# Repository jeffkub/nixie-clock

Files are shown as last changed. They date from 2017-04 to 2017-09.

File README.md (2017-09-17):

# nixie-clock

An open source nixie clock with GPS time synchronization.

## Enclosure

The enclosure design has been moved to Fusion 360.  The files in the hardware folder are out of date and will be removed at some point.

1. [Enclosure](http://a360.co/2x962o5)
2. [PCB](http://a360.co/2x9v2f3)
3. [Assembly](http://a360.co/2y7SgBr)

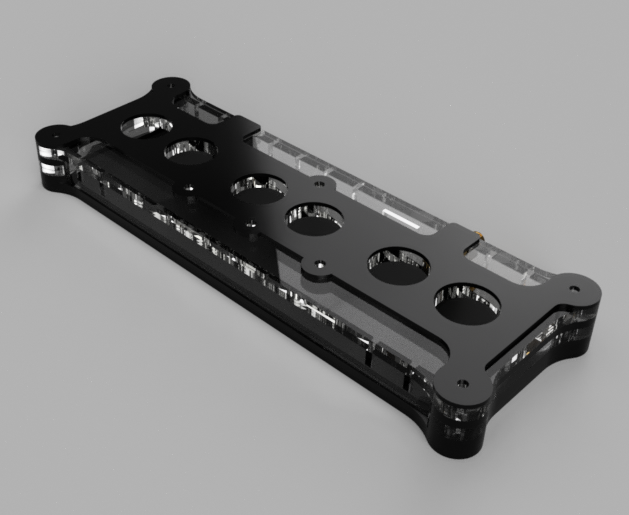
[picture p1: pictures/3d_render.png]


## Build Instructions

The code was built on Ubuntu 16.04.  The [STM32Cube F3 library V1.9.0](http://www.st.com/content/st_com/en/products/embedded-software/mcus-embedded-software/stm32-embedded-software/stm32cube-embedded-software/stm32cubef3.html) will need to be installed to the `/opt/` directory.  The following apt packages are required.

```
cmake
gcc-arm-none-eabi
gdb-arm-none-eabi
```

To build the code.

```bash
mkdir firmware/nixie-clock/release
cd firmware/nixie-clock/release
cmake -DSTM32_CHIP=STM32F302C8 -DCMAKE_TOOLCHAIN_FILE=../../cmake/gcc_stm32.cmake -DSTM32Cube_DIR=/opt/STM32Cube_FW_F3_V1.9.0/ -DCMAKE_BUILD_TYPE=Release ..
make
```

To build for debugging.

```bash
mkdir firmware/nixie-clock/debug
cd firmware/nixie-clock/debug
cmake -DSTM32_CHIP=STM32F302C8 -DCMAKE_TOOLCHAIN_FILE=../../cmake/gcc_stm32.cmake -DSTM32Cube_DIR=/opt/STM32Cube_FW_F3_V1.9.0/ -DCMAKE_BUILD_TYPE=Debug ..
make
```

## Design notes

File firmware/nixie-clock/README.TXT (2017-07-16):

cmake -DSTM32_CHIP=STM32F302C8 -DCMAKE_TOOLCHAIN_FILE=../../cmake/gcc_stm32.cmake -DSTM32Cube_DIR=/opt/STM32Cube_FW_F3_V1.9.0/ -DCMAKE_BUILD_TYPE=Debug ..

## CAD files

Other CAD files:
mechanical/NixieClock.dwg
mechanical/Back.ipt
mechanical/Base1.ipt
mechanical/Base2.ipt
mechanical/Bumper.ipt
mechanical/Cover.ipt
mechanical/Front.ipt
mechanical/IN-14.ipt
mechanical/M3Nut.ipt
mechanical/M3x25mm.ipt
mechanical/MainPCB.ipt
mechanical/NixieClock.iam
mechanical/PCB.iam
mechanical/Side.iam
mechanical/Spacer1.ipt
mechanical/Spacer2.ipt
mechanical/Top.ipt
mechanical/TubePCB.ipt

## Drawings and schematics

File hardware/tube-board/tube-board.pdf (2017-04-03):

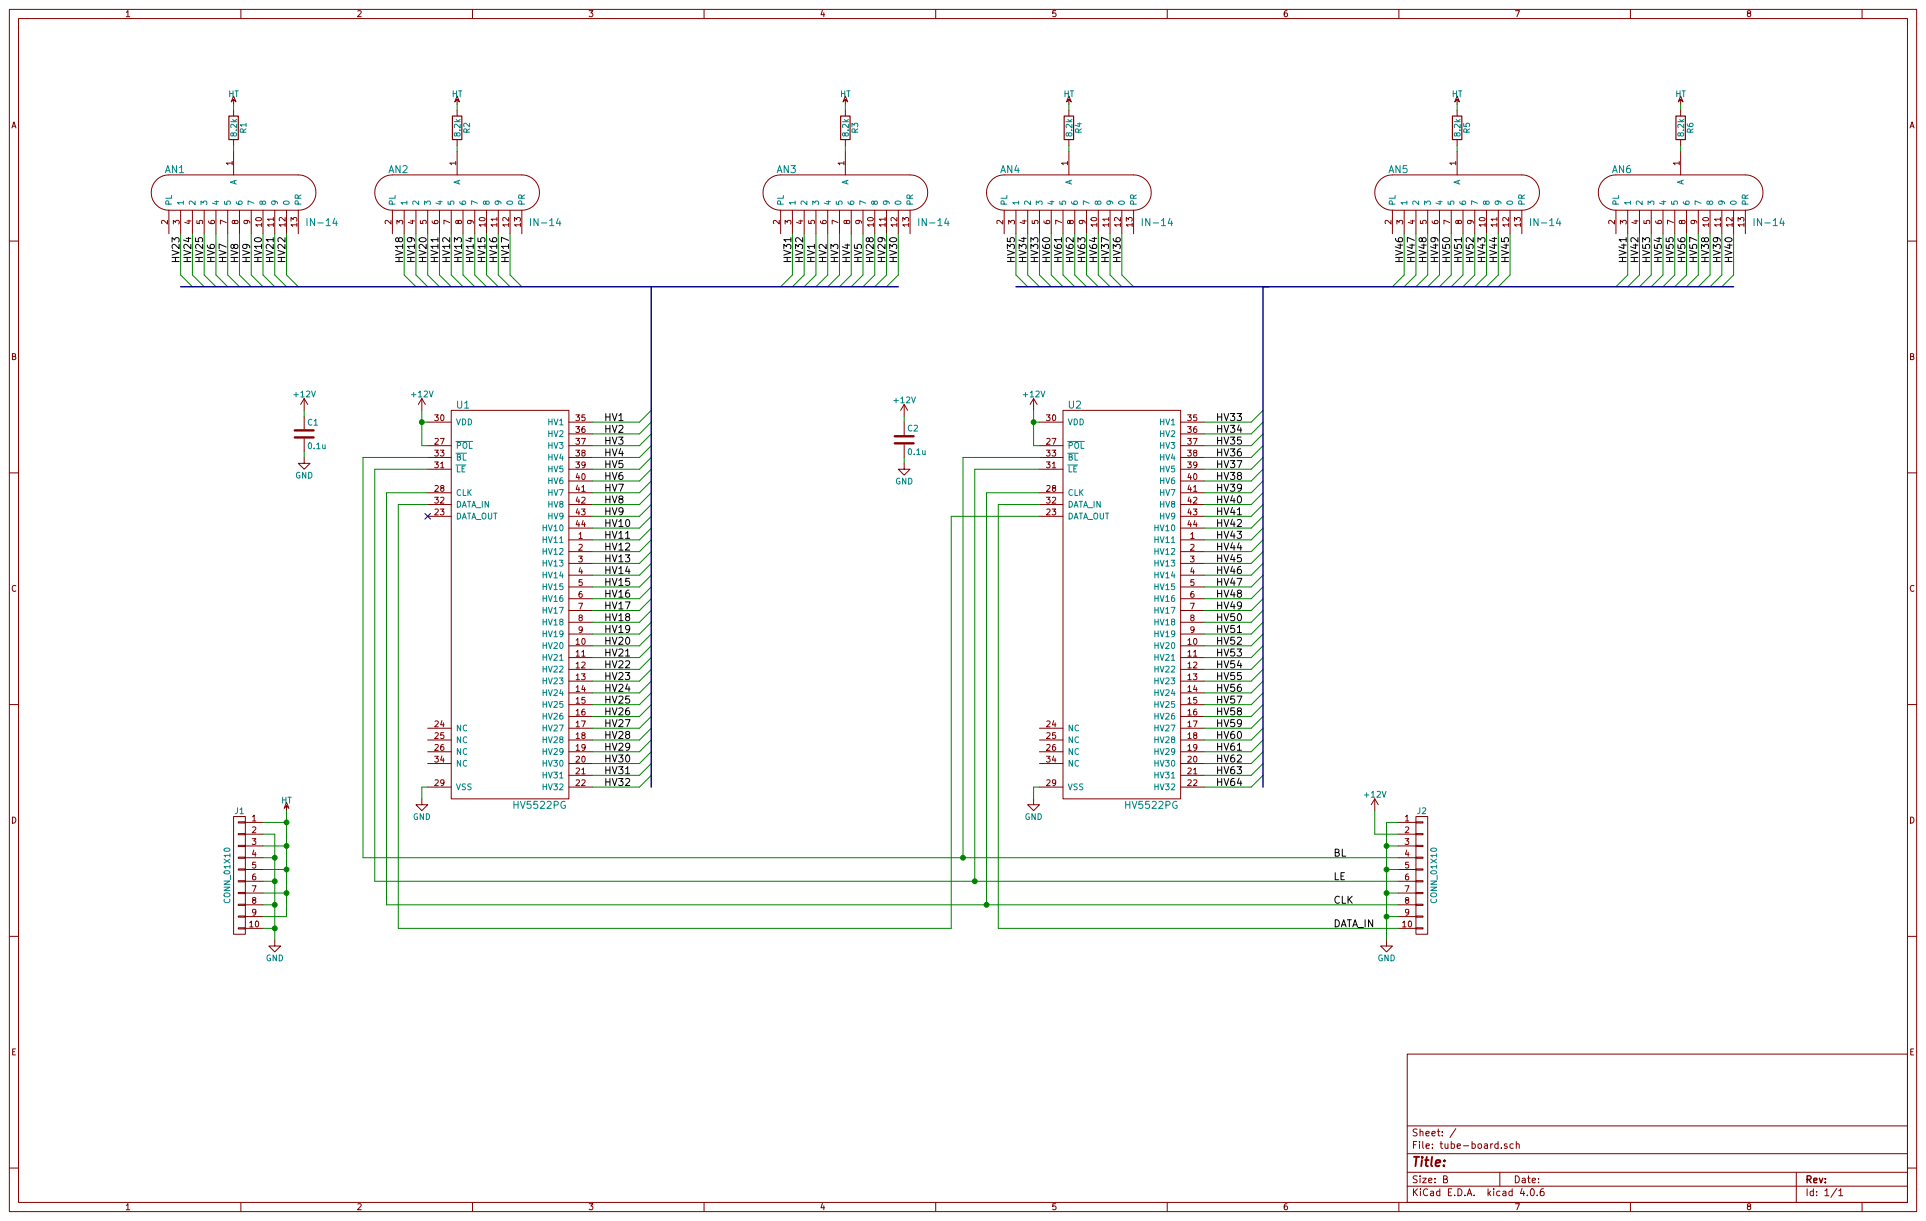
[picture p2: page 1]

Id: 1/1 Title: File: tube-board.sch Sheet: /

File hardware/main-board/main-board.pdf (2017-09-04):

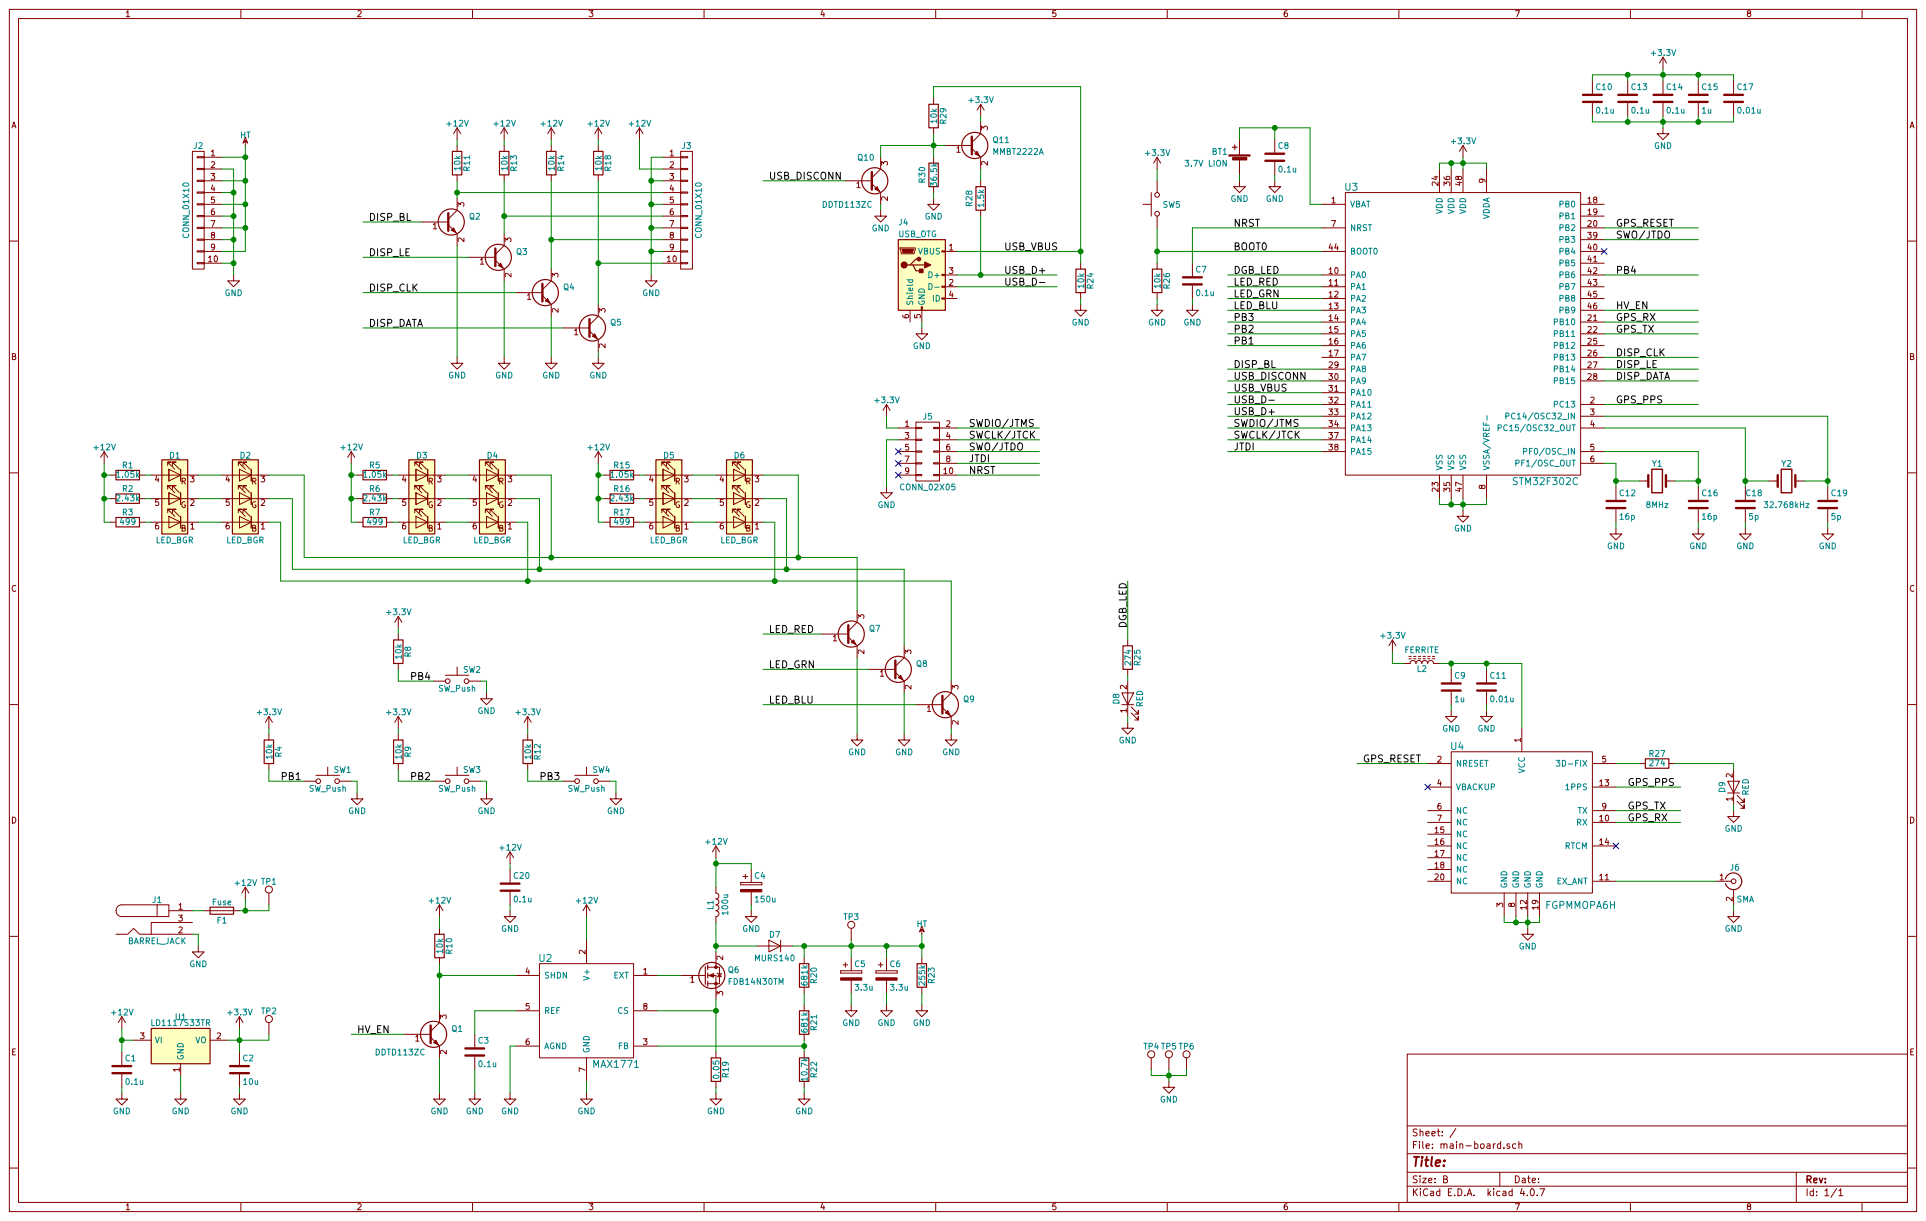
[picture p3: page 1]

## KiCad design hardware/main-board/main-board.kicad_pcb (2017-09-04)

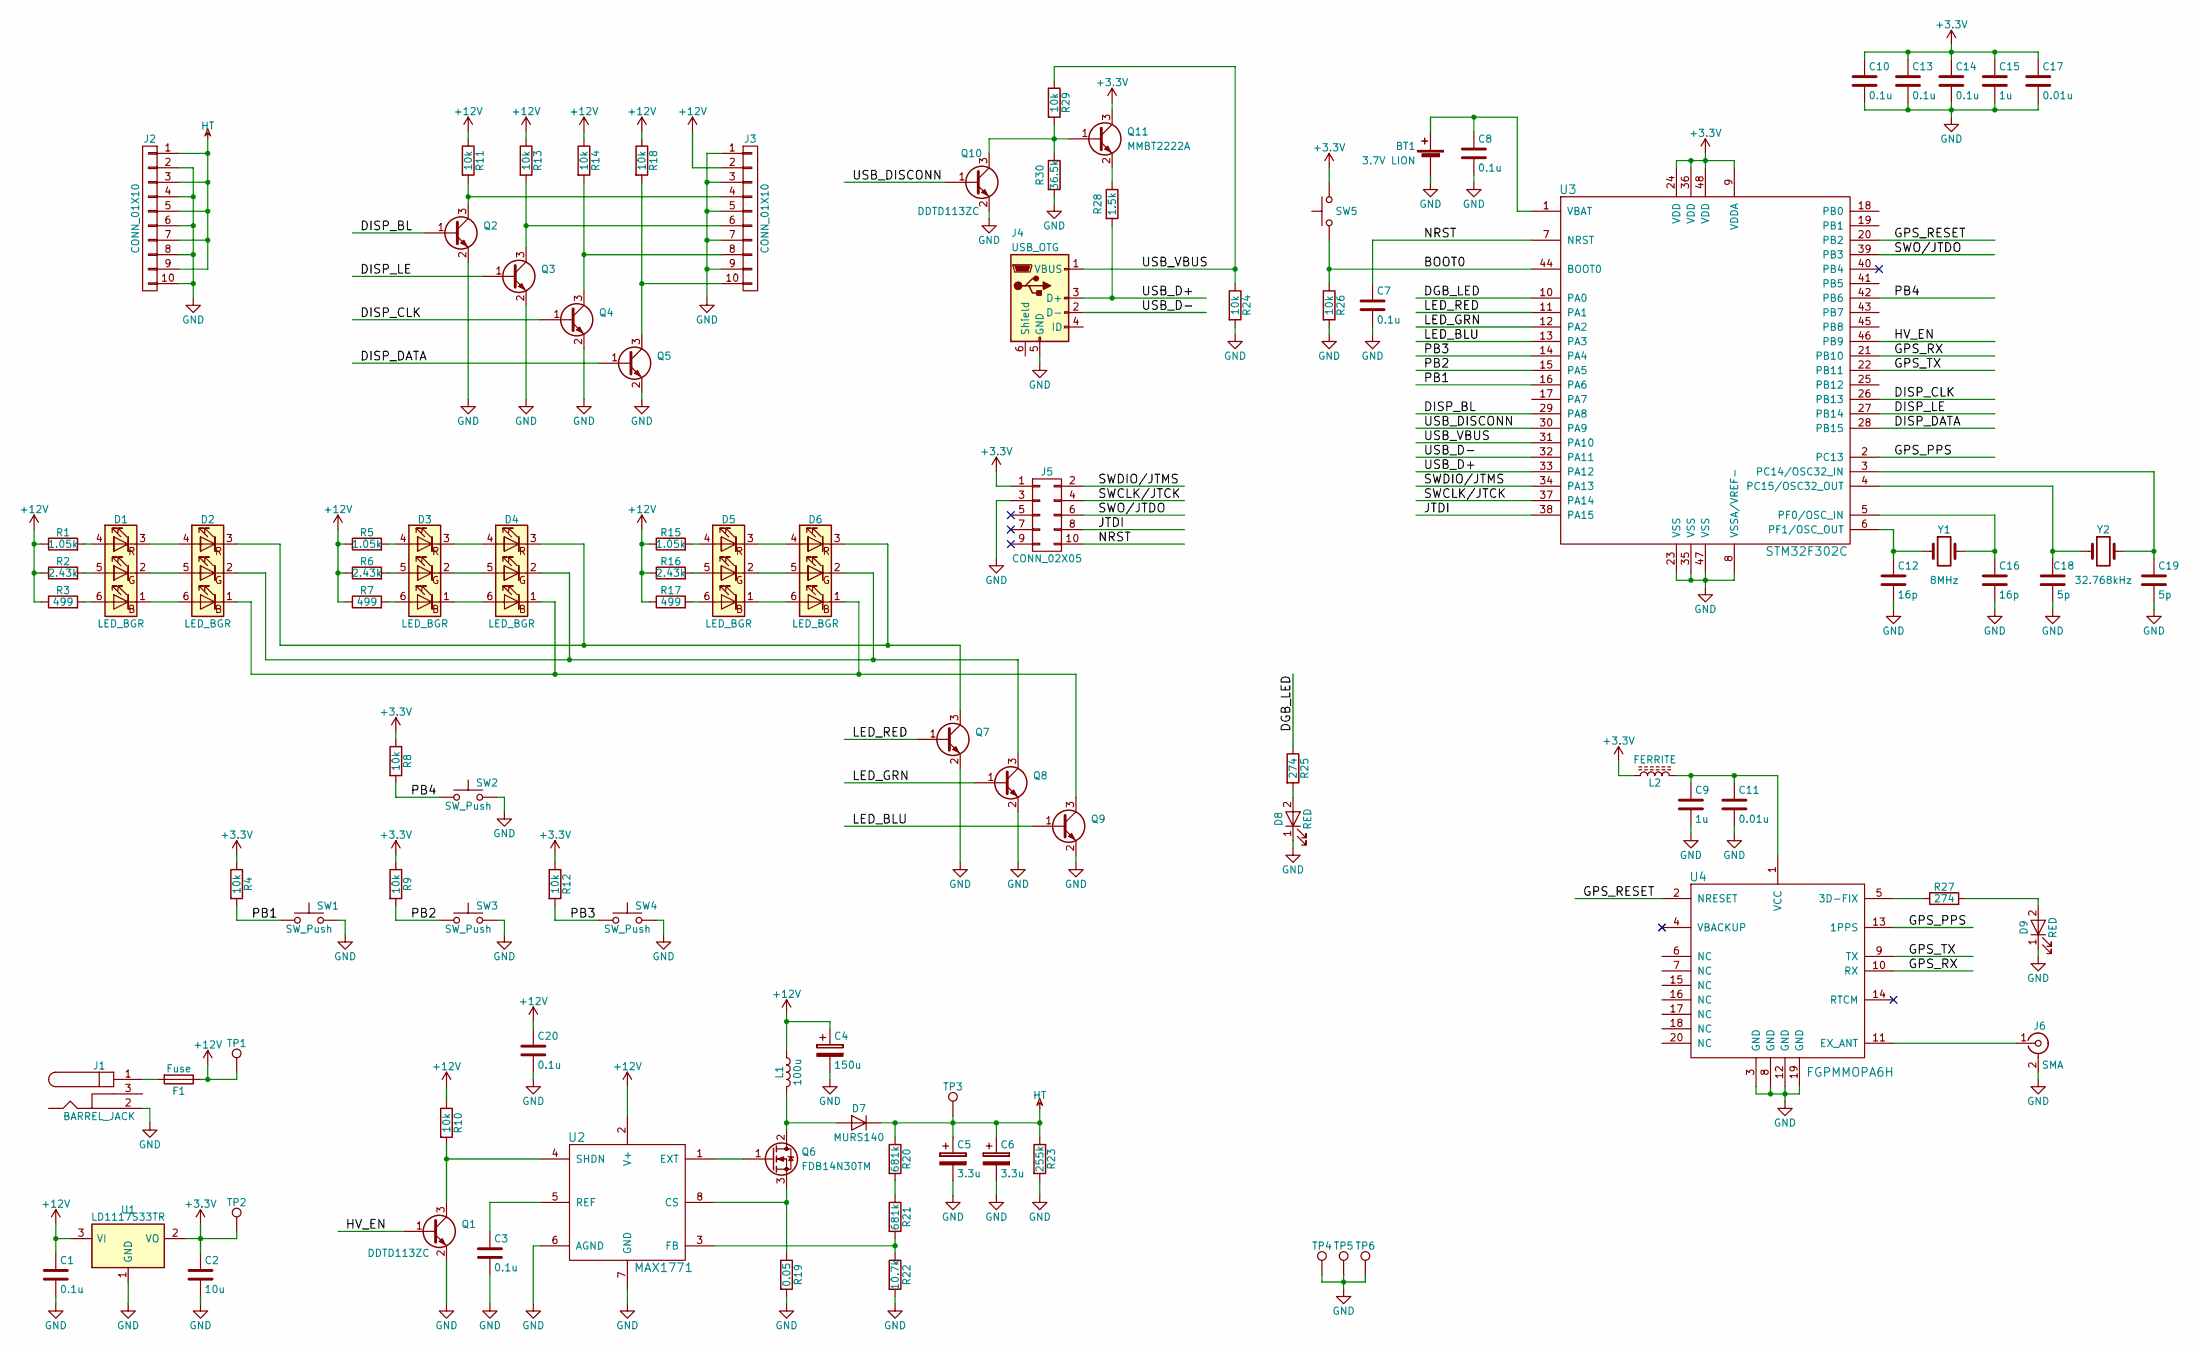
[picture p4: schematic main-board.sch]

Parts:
BT1: 3.7V LION; S8411-45R; Part 952-1745-1-ND
C1, C3, C7, C8, C10, C13, C14, C20: 0.1u; C_0603; Part 311-1344-1-ND
C2: 10u; C_0805; Part 311-1460-1-ND
C4: 150u; CP_Radial_D6.3mm_P2.50mm; Part P15352CT-ND
C5, C6: 3.3u; CP_Radial_D6.3mm_P2.50mm; Part 493-12639-1-ND
C9, C15: 1u; C_0805; Part 311-1365-1-ND
C11, C17: 0.01u; C_0603; Part 311-1085-1-ND
C12, C16: 16p; C_0603; Part 311-1751-1-ND
C18, C19: 5p; C_0603; Part 311-1054-1-ND
D1, D2, D3, D4, D5, D6: LED_BGR; PLCC-6; Part 516-3281-1-ND
D7: MURS140; D_SMB_Standard; Part MURS140-FDICT-ND
D8, D9: RED; D_1206; Part 160-1405-1-ND
F1: Fuse; 01110501Z; Part F4189-ND
J1: BARREL_JACK; PJ-002AH-SMT-TR; Part CP-002AHPJCT-ND
J2, J3: CONN_01X10; 8-188275-0; Part A99476CT-ND
J4: USB_OTG; 10118192; Part 609-4613-1-ND
J5: CONN_02X05; TC2050-IDC; Part NA
J6: SMA; SMA_THT_Jack_Straight; Part CONSMA002-L-ND
L1: 100u; DO3316P; Part 994-DO3316P-104MLD
L2: FERRITE; R_0805; Part 490-1054-1-ND
Q1, Q2, Q3, Q4, Q5, Q7, Q8, Q9, Q10: DDTD113ZC; SOT-23; Part DDTD113ZC-7FDICT-ND
Q6: FDB14N30TM; TO-263-2; Part FDB14N30TMCT-ND
Q11: MMBT2222A; SOT-23; Part MMBT2222A-FDICT-ND
R1, R5, R15: 1.05k; R_0805; Part 311-1.05KCRCT-ND
R2, R6, R16: 2.43k; R_0805; Part 311-2.43KCRCT-ND
R3, R7, R17: 499; R_0805; Part 311-499CRCT-ND
R4, R8, R9, R10, R11, R12, R13, R14, R18, R24, R26, R29: 10k; R_0805; Part 311-10.0KCRCT-ND
R19: 0.05; R_1206; Part 311-.05LWCT-ND
R20, R21: 681k; R_1206; Part 311-681KFRCT-ND
R22: 10.7k; R_1206; Part 311-10.7KFRCT-ND
R23: 255k; R_1206; Part 311-255KFRCT-ND
R25, R27: 274; R_0805; Part 311-274CRCT-ND
R28: 1.5k; R_0805; Part 311-1.50KCRCT-ND
R30: 36.5k; R_0805; Part 311-36.5KCRCT-ND
SW1, SW2, SW3, SW4: SW_Push; SW_PUSH_6mm; Part EG2505-ND
SW5: SW_Push; TL1105SF160Q; Part EG1839-ND
TP1, TP2, TP3, TP4, TP5, TP6: TP; Measurement_Point_Round-TH_Small; Part NA
U1: LD1117S33TR; SOT-223; Part 497-1242-1-ND
U2: MAX1771; SOIC-8_3.9x4.9mm_Pitch1.27mm; Part MAX1771CSA+CT-ND
U3: STM32F302C; LQFP-48_7x7mm_Pitch0.5mm; Part 497-14699-ND
U4: FGPMMOPA6H; Part 790
Y1: 8MHz; Crystal_SMD_HC49-SD; Part 535-10212-1-ND
Y2: 32.768kHz; ABS07; Part 535-9542-1-ND

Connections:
+3V3: C2.1, C10.1, C13.1, C14.1, C15.1, C17.1, J5.1, L2.1, Q11.3 (C), R4.1, R8.1, R9.1, R12.1, SW5.1, TP2.1, U1.2 (VO), U3.9 (VDDA), U3.24 (VDD), U3.36 (VDD), U3.48 (VDD)
+12V: C1.1, C4.1, C20.1, F1.1, J3.2, L1.1, R1.1, R2.1, R3.1, R5.1, R6.1, R7.1, R10.1, R11.1, R13.1, R14.1, R15.1, R16.1, R17.1, R18.1, TP1.1, U1.3 (VI), U2.2 (V+)
/BOOT0: R26.1, SW5.2, U3.44 (BOOT0)
/DGB_LED: R25.1, U3.10 (PA0)
/DISP_BL: Q2.1 (B), U3.29 (PA8)
/DISP_CLK: Q4.1 (B), U3.26 (PB13)
/DISP_DATA: Q5.1 (B), U3.28 (PB15)
/DISP_LE: Q3.1 (B), U3.27 (PB14)
/GPS_PPS: U3.2 (PC13), U4.13 (1PPS)
/GPS_RESET: U3.20 (PB2), U4.2 (NRESET)
/GPS_RX: U3.21 (PB10), U4.10 (RX)
/GPS_TX: U3.22 (PB11), U4.9 (TX)
/HV_EN: Q1.1 (B), U3.46 (PB9)
/JTDI: J5.8, U3.38 (PA15)
/LED_BLU: Q9.1 (B), U3.13 (PA3)
/LED_GRN: Q8.1 (B), U3.12 (PA2)
/LED_RED: Q7.1 (B), U3.11 (PA1)
/NRST: C7.1, J5.10, U3.7 (NRST)
/PB1: R4.2, SW1.1, U3.16 (PA6)
/PB2: R9.2, SW3.1, U3.15 (PA5)
/PB3: R12.2, SW4.1, U3.14 (PA4)
/PB4: R8.2, SW2.1, U3.42 (PB6)
/SWCLK/JTCK: J5.4, U3.37 (PA14)
/SWDIO/JTMS: J5.2, U3.34 (PA13)
/SWO/JTDO: J5.6, U3.39 (PB3)
/USB_D+: J4.3 (D+), R28.2, U3.33 (PA12)
/USB_D-: J4.2 (D-), U3.32 (PA11)
/USB_DISCONN: Q10.1 (B), U3.30 (PA9)
/USB_VBUS: J4.1 (VBUS), R24.1, R29.1, U3.31 (PA10)
GND: BT1.2 (-), C1.2, C2.2, C3.2, C4.2, C5.2, C6.2, C7.2, C8.2, C9.2, C10.2, C11.2, C12.2, C13.2, C14.2, C15.2, C16.2, C17.2, C18.2, C19.2, C20.2, D8.1 (K), D9.1 (K), J1.2, J2.2, J2.4, J2.6, J2.8, J2.10, J3.1, J3.3, J3.5, J3.7, J3.9, J4.5 (GND), J5.3, J6.2 (Ext), Q1.2 (E), Q2.2 (E), Q3.2 (E), Q4.2 (E), Q5.2 (E), Q7.2 (E), Q8.2 (E), Q9.2 (E), Q10.2 (E), R19.2, R22.2, R23.2, R24.2, R26.2, R30.2, SW1.2, SW2.2, SW3.2, SW4.2, TP4.1, TP5.1, TP6.1, U1.1 (GND), U2.6 (AGND), U2.7 (GND), U3.8 (VSSA/VREF-), U3.23 (VSS), U3.35 (VSS), U3.47 (VSS), U4.3 (GND), U4.8 (GND), U4.12 (GND), U4.19 (GND)
HT: C5.1, C6.1, D7.1 (K), J2.1, J2.3, J2.5, J2.7, J2.9, R20.1, R23.1, TP3.1
unnamed: BT1.1 (+), C8.1, U3.1 (VBAT)
unnamed: C3.1, U2.5 (REF)
unnamed: C9.1, C11.1, L2.2, U4.1 (VCC)
unnamed: C12.1, U3.6 (PF1/OSC_OUT), Y1.1
unnamed: C16.1, U3.5 (PF0/OSC_IN), Y1.2
unnamed: C18.1, U3.4 (PC15/OSC32_OUT), Y2.1
unnamed: C19.1, U3.3 (PC14/OSC32_IN), Y2.2
unnamed: D1.1 (BK), D2.6 (BA)
unnamed: D1.2 (GK), D2.5 (GA)
unnamed: D1.3 (RK), D2.4 (RA)
unnamed: D1.4 (RA), R1.2
unnamed: D1.5 (GA), R2.2
unnamed: D1.6 (BA), R3.2
unnamed: D2.1 (BK), D4.1 (BK), D6.1 (BK), Q9.3 (C)
unnamed: D2.2 (GK), D4.2 (GK), D6.2 (GK), Q8.3 (C)
unnamed: D2.3 (RK), D4.3 (RK), D6.3 (RK), Q7.3 (C)
unnamed: D3.1 (BK), D4.6 (BA)
unnamed: D3.2 (GK), D4.5 (GA)
unnamed: D3.3 (RK), D4.4 (RA)
unnamed: D3.4 (RA), R5.2
unnamed: D3.5 (GA), R6.2
unnamed: D3.6 (BA), R7.2
unnamed: D5.1 (BK), D6.6 (BA)
unnamed: D5.2 (GK), D6.5 (GA)
unnamed: D5.3 (RK), D6.4 (RA)
unnamed: D5.4 (RA), R15.2
unnamed: D5.5 (GA), R16.2
unnamed: D5.6 (BA), R17.2
unnamed: D7.2 (A), L1.2, Q6.2 (D)
unnamed: D8.2 (A), R25.2
unnamed: D9.2 (A), R27.2
unnamed: F1.2, J1.1
unnamed: J3.4, Q2.3 (C), R11.2
unnamed: J3.6, Q3.3 (C), R13.2
unnamed: J3.8, Q4.3 (C), R14.2
unnamed: J3.10, Q5.3 (C), R18.2
unnamed: J6.1 (In), U4.11 (EX_ANT)
unnamed: Q1.3 (C), R10.2, U2.4 (SHDN)
unnamed: Q6.1 (G), U2.1 (EXT)
unnamed: Q6.3 (S), R19.1, U2.8 (CS)
unnamed: Q10.3 (C), Q11.1 (B), R29.2, R30.1
unnamed: Q11.2 (E), R28.1
unnamed: R20.2, R21.1
unnamed: R21.2, R22.1, U2.3 (FB)
unnamed: R27.1, U4.5 (3D-FIX)

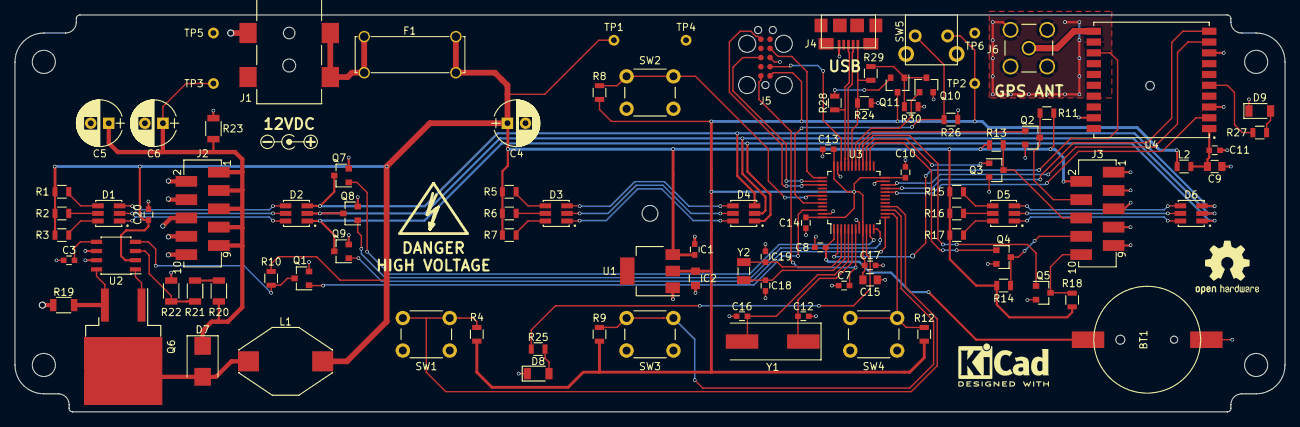
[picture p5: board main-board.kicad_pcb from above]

Board: 2 copper layers, 176.0 x 55.0 mm, 97 parts (0 on the bottom side), 76 nets.

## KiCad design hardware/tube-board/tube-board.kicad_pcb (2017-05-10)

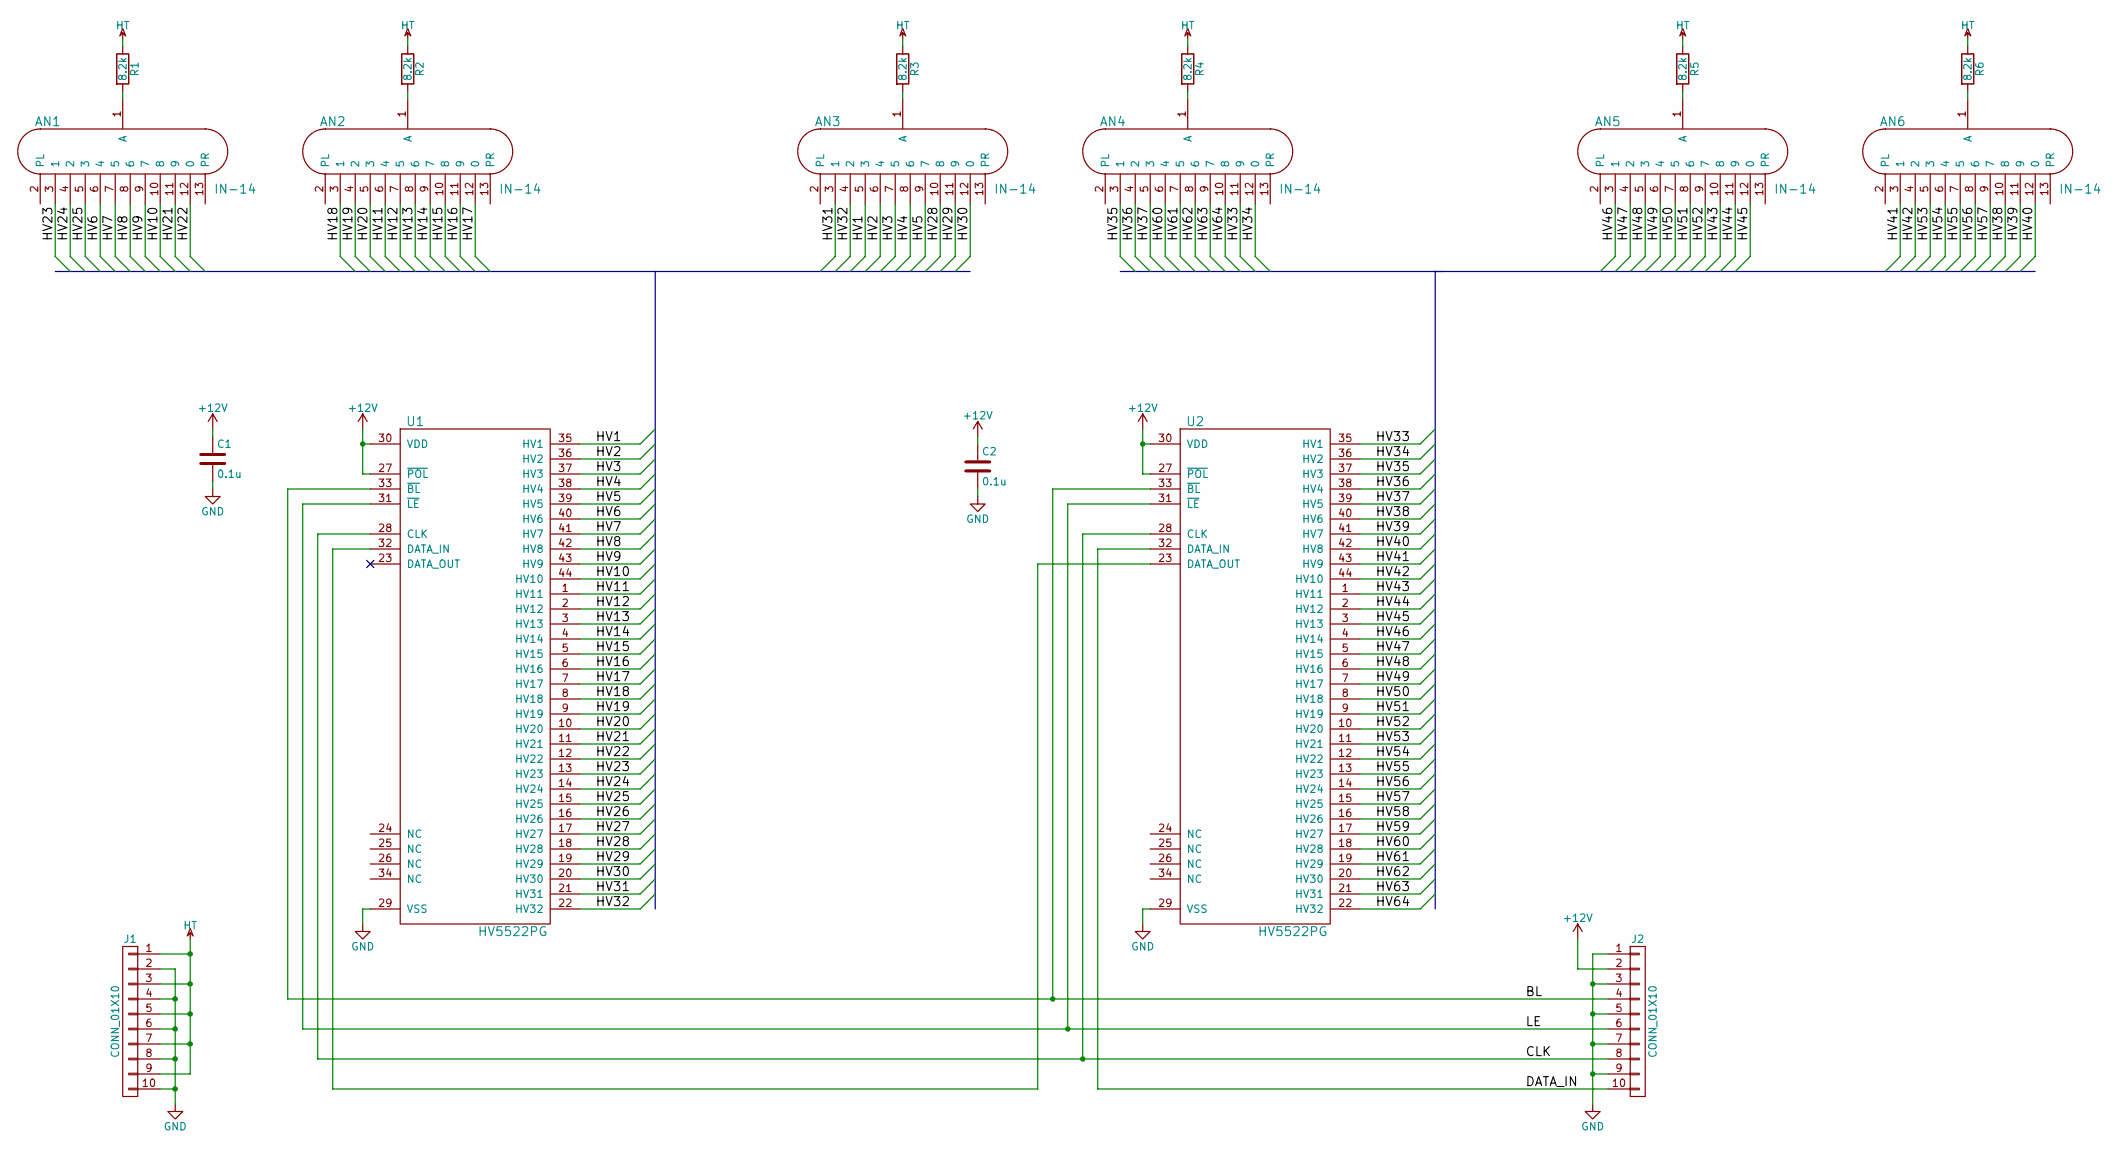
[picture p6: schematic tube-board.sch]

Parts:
AN1, AN2, AN3, AN4, AN5, AN6: IN-14
C1, C2: 0.1u; C_0603; Part 311-1344-1-ND
J1, J2: CONN_01X10; 1-338728-0; Part A116183CT-ND
R1, R2, R3, R4, R5, R6: 8.2k; R_1206; Part 311-8.20KFRCT-ND
U1, U2: HV5522PG; LQFP-44_10x10mm_Pitch0.8mm; Part 689-HV5522PG-G

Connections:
+12V: C1.1, C2.1, J2.2, U1.27 (~POL), U1.30 (VDD), U2.27 (~POL), U2.30 (VDD)
/BL: J2.4, U1.33 (~BL), U2.33 (~BL)
/CLK: J2.8, U1.28 (CLK), U2.28 (CLK)
/DATA_IN: J2.10, U2.32 (DATA_IN)
/HV1: AN3.5 (3), U1.35 (HV1)
/HV2: AN3.6 (4), U1.36 (HV2)
/HV3: AN3.7 (5), U1.37 (HV3)
/HV4: AN3.8 (6), U1.38 (HV4)
/HV5: AN3.9 (7), U1.39 (HV5)
/HV6: AN1.6 (4), U1.40 (HV6)
/HV7: AN1.7 (5), U1.41 (HV7)
/HV8: AN1.8 (6), U1.42 (HV8)
/HV9: AN1.9 (7), U1.43 (HV9)
/HV10: AN1.10 (8), U1.44 (HV10)
/HV11: AN2.6 (4), U1.1 (HV11)
/HV12: AN2.7 (5), U1.2 (HV12)
/HV13: AN2.8 (6), U1.3 (HV13)
/HV14: AN2.9 (7), U1.4 (HV14)
/HV15: AN2.10 (8), U1.5 (HV15)
/HV16: AN2.11 (9), U1.6 (HV16)
/HV17: AN2.12 (0), U1.7 (HV17)
/HV18: AN2.3 (1), U1.8 (HV18)
/HV19: AN2.4 (2), U1.9 (HV19)
/HV20: AN2.5 (3), U1.10 (HV20)
/HV21: AN1.11 (9), U1.11 (HV21)
/HV22: AN1.12 (0), U1.12 (HV22)
/HV23: AN1.3 (1), U1.13 (HV23)
/HV24: AN1.4 (2), U1.14 (HV24)
/HV25: AN1.5 (3), U1.15 (HV25)
/HV26: U1.16 (HV26)
/HV27: U1.17 (HV27)
/HV28: AN3.10 (8), U1.18 (HV28)
/HV29: AN3.11 (9), U1.19 (HV29)
/HV30: AN3.12 (0), U1.20 (HV30)
/HV31: AN3.3 (1), U1.21 (HV31)
/HV32: AN3.4 (2), U1.22 (HV32)
/HV33: AN4.11 (9), U2.35 (HV1)
/HV34: AN4.12 (0), U2.36 (HV2)
/HV35: AN4.3 (1), U2.37 (HV3)
/HV36: AN4.4 (2), U2.38 (HV4)
/HV37: AN4.5 (3), U2.39 (HV5)
/HV38: AN6.10 (8), U2.40 (HV6)
/HV39: AN6.11 (9), U2.41 (HV7)
/HV40: AN6.12 (0), U2.42 (HV8)
/HV41: AN6.3 (1), U2.43 (HV9)
/HV42: AN6.4 (2), U2.44 (HV10)
/HV43: AN5.10 (8), U2.1 (HV11)
/HV44: AN5.11 (9), U2.2 (HV12)
/HV45: AN5.12 (0), U2.3 (HV13)
/HV46: AN5.3 (1), U2.4 (HV14)
/HV47: AN5.4 (2), U2.5 (HV15)
/HV48: AN5.5 (3), U2.6 (HV16)
/HV49: AN5.6 (4), U2.7 (HV17)
/HV50: AN5.7 (5), U2.8 (HV18)
/HV51: AN5.8 (6), U2.9 (HV19)
/HV52: AN5.9 (7), U2.10 (HV20)
/HV53: AN6.5 (3), U2.11 (HV21)
/HV54: AN6.6 (4), U2.12 (HV22)
/HV55: AN6.7 (5), U2.13 (HV23)
/HV56: AN6.8 (6), U2.14 (HV24)
/HV57: AN6.9 (7), U2.15 (HV25)
/HV58: U2.16 (HV26)
/HV59: U2.17 (HV27)
/HV60: AN4.6 (4), U2.18 (HV28)
/HV61: AN4.7 (5), U2.19 (HV29)
/HV62: AN4.8 (6), U2.20 (HV30)
/HV63: AN4.9 (7), U2.21 (HV31)
/HV64: AN4.10 (8), U2.22 (HV32)
/LE: J2.6, U1.31 (~LE), U2.31 (~LE)
GND: C1.2, C2.2, J1.2, J1.4, J1.6, J1.8, J1.10, J2.1, J2.3, J2.5, J2.7, J2.9, U1.29 (VSS), U2.29 (VSS)
HT: J1.1, J1.3, J1.5, J1.7, J1.9, R1.1, R2.1, R3.1, R4.1, R5.1, R6.1
unnamed: AN1.1 (A), R1.2
unnamed: AN2.1 (A), R2.2
unnamed: AN3.1 (A), R3.2
unnamed: AN4.1 (A), R4.2
unnamed: AN5.1 (A), R5.2
unnamed: AN6.1 (A), R6.2
unnamed: U1.32 (DATA_IN), U2.23 (DATA_OUT)

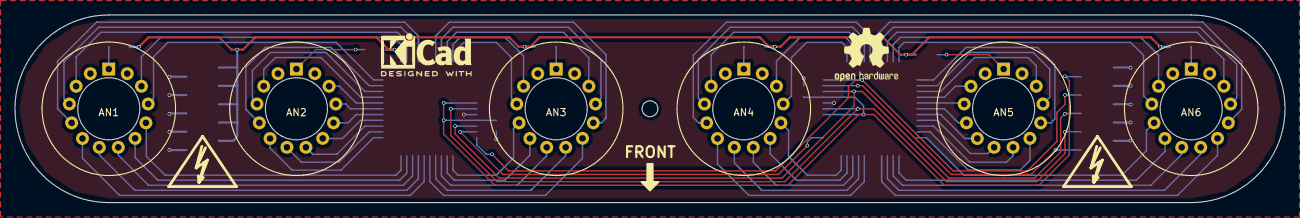
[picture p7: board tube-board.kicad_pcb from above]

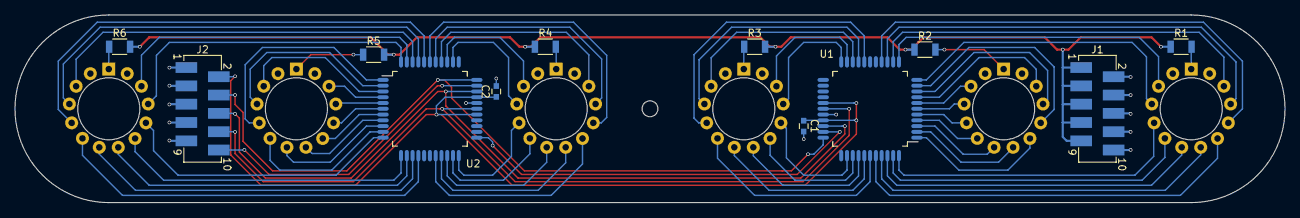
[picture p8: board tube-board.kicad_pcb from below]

Board: 2 copper layers, 176.0 x 26.0 mm, 18 parts (12 on the bottom side), 74 nets.

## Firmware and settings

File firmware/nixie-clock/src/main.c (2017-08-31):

/*******************************************************************************
MIT License

Copyright (c) 2017 Jeff Kubascik

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
THE SOFTWARE IS PROVIDED "AS IS", WITHOUT WARRANTY OF ANY KIND, EXPRESS OR
IMPLIED, INCLUDING BUT NOT LIMITED TO THE WARRANTIES OF MERCHANTABILITY,
FITNESS FOR A PARTICULAR PURPOSE AND NONINFRINGEMENT. IN NO EVENT SHALL THE
AUTHORS OR COPYRIGHT HOLDERS BE LIABLE FOR ANY CLAIM, DAMAGES OR OTHER
LIABILITY, WHETHER IN AN ACTION OF CONTRACT, TORT OR OTHERWISE, ARISING FROM,
OUT OF OR IN CONNECTION WITH THE SOFTWARE OR THE USE OR OTHER DEALINGS IN THE
SOFTWARE.
*******************************************************************************/

/* Includes *******************************************************************/
#include "globals.h"
#include "stm32f3xx_hal.h"
#include "usb_device.h"

#include "FreeRTOS.h"
#include "task.h"

#include "debug.h"
#include "pwm.h"
#include "spi.h"
#include "uart.h"
#include "rtc.h"
#include "timezone.h"
#include "gps.h"
#include "nixieDriver.h"
#include "color.h"


/* Private variables **********************************************************/
static const timeZoneRule_t timezoneDST =
    { "EDT", Second, Sun, Mar, 2, -4 * 60 };

static const timeZoneRule_t timezoneSTD =
    { "EST", First,  Sun, Nov, 2, -5 * 60 };

static TaskHandle_t mainTaskHandle;
static TaskHandle_t ledTaskHandle;


/* Private function prototypes ************************************************/
static void systemClockConfig(void);
static void gpioInit(void);

static void mainTask(void * argument);
static void ledTask(void * argument);

extern void initialise_monitor_handles(void);
extern void HAL_TIM_MspPostInit(TIM_HandleTypeDef *htim);


/* Private function definitions ***********************************************/
static void systemClockConfig(void)
{
    RCC_OscInitTypeDef       rcc_osc;
    RCC_ClkInitTypeDef       rcc_clk;
    RCC_PeriphCLKInitTypeDef periph_clk;

    /* Initializes the CPU, AHB and APB busses clocks */
    rcc_osc.OscillatorType = RCC_OSCILLATORTYPE_LSI |
                             RCC_OSCILLATORTYPE_HSE;
    rcc_osc.HSEState       = RCC_HSE_ON;
    rcc_osc.HSEPredivValue = RCC_HSE_PREDIV_DIV1;
    rcc_osc.HSIState       = RCC_HSI_ON;
    rcc_osc.LSIState       = RCC_LSI_ON;
    rcc_osc.PLL.PLLState   = RCC_PLL_ON;
    rcc_osc.PLL.PLLSource  = RCC_PLLSOURCE_HSE;
    rcc_osc.PLL.PLLMUL     = RCC_PLL_MUL9;
    HAL_RCC_OscConfig(&rcc_osc);

    /* Initializes the CPU, AHB and APB busses clocks */
    rcc_clk.ClockType      = RCC_CLOCKTYPE_HCLK   |
                             RCC_CLOCKTYPE_SYSCLK |
                             RCC_CLOCKTYPE_PCLK1  |
                             RCC_CLOCKTYPE_PCLK2;
    rcc_clk.SYSCLKSource   = RCC_SYSCLKSOURCE_PLLCLK;
    rcc_clk.AHBCLKDivider  = RCC_SYSCLK_DIV1;
    rcc_clk.APB1CLKDivider = RCC_HCLK_DIV4;
    rcc_clk.APB2CLKDivider = RCC_HCLK_DIV1;
    HAL_RCC_ClockConfig(&rcc_clk, FLASH_LATENCY_2);

    periph_clk.PeriphClockSelection = RCC_PERIPHCLK_USB |
                                      RCC_PERIPHCLK_RTC;
    periph_clk.RTCClockSelection    = RCC_RTCCLKSOURCE_LSE;
    periph_clk.USBClockSelection    = RCC_USBCLKSOURCE_PLL_DIV1_5;
    HAL_RCCEx_PeriphCLKConfig(&periph_clk);

    /* Configure the Systick interrupt time */
    HAL_SYSTICK_Config(HAL_RCC_GetHCLKFreq()/configTICK_RATE_HZ);

    /* Configure the Systick */
    HAL_SYSTICK_CLKSourceConfig(SYSTICK_CLKSOURCE_HCLK);

    /* SysTick_IRQn interrupt configuration */
    HAL_NVIC_SetPriority(SysTick_IRQn, SYSTICK_IRQ_PRIORITY, 0);

    debug_printf("SysClock: %u Hz\n", (unsigned)HAL_RCC_GetSysClockFreq());
    debug_printf("HCLK    : %u Hz\n", (unsigned)HAL_RCC_GetHCLKFreq());
    debug_printf("PCLK1   : %u Hz\n", (unsigned)HAL_RCC_GetPCLK1Freq());
    debug_printf("PCLK2   : %u Hz\n", (unsigned)HAL_RCC_GetPCLK2Freq());

    return;
}

static void gpioInit(void)
{
    GPIO_InitTypeDef gpio;

    /* GPIO Ports Clock Enable */
    __HAL_RCC_GPIOC_CLK_ENABLE();
    __HAL_RCC_GPIOF_CLK_ENABLE();
    __HAL_RCC_GPIOA_CLK_ENABLE();
    __HAL_RCC_GPIOB_CLK_ENABLE();

    /*Configure GPIO pin Output Level */
    HAL_GPIO_WritePin(GPIOB, GPS_RESET_Pin | DISP_LE_Pin | HV_EN_Pin, GPIO_PIN_RESET);

    /*Configure GPIO pin Output Level */
    HAL_GPIO_WritePin(DISP_BL_GPIO_Port, DISP_BL_Pin, GPIO_PIN_SET);

    /*Configure GPIO pins */
    gpio.Pin  = PB3_Pin | PB2_Pin | PB1_Pin | USB_VBUS_Pin;
    gpio.Mode = GPIO_MODE_INPUT;
    gpio.Pull = GPIO_NOPULL;
    HAL_GPIO_Init(GPIOA, &gpio);

    gpio.Pin   = GPS_RESET_Pin | DISP_LE_Pin | HV_EN_Pin;
    gpio.Mode  = GPIO_MODE_OUTPUT_PP;
    gpio.Pull  = GPIO_NOPULL;
    gpio.Speed = GPIO_SPEED_FREQ_LOW;
    HAL_GPIO_Init(GPIOB, &gpio);

    gpio.Pin   = DISP_BL_Pin;
    gpio.Mode  = GPIO_MODE_OUTPUT_PP;
    gpio.Pull  = GPIO_NOPULL;
    gpio.Speed = GPIO_SPEED_FREQ_LOW;
    HAL_GPIO_Init(DISP_BL_GPIO_Port, &gpio);

    gpio.Pin  = PB4_Pin;
    gpio.Mode = GPIO_MODE_INPUT;
    gpio.Pull = GPIO_NOPULL;
    HAL_GPIO_Init(PB4_GPIO_Port, &gpio);

    gpio.Pin  = GPS_PPS_Pin;
    gpio.Mode = GPIO_MODE_IT_RISING;
    gpio.Pull = GPIO_NOPULL;
    HAL_GPIO_Init(GPS_PPS_GPIO_Port, &gpio);

    /* TIM2 pin configuration */
    gpio.Pin       = DBG_LED_Pin | LED_RED_Pin | LED_GRN_Pin | LED_BLU_Pin;
    gpio.Mode      = GPIO_MODE_AF_PP;
    gpio.Pull      = GPIO_NOPULL;
    gpio.Speed     = GPIO_SPEED_FREQ_LOW;
    gpio.Alternate = GPIO_AF1_TIM2;
    HAL_GPIO_Init(DBG_LED_GPIO_Port, &gpio);

    /* SPI2 pin configuration */
    gpio.Pin       = DISP_CLK_Pin | DISP_DATA_Pin;
    gpio.Mode      = GPIO_MODE_AF_PP;
    gpio.Pull      = GPIO_NOPULL;
    gpio.Speed     = GPIO_SPEED_FREQ_HIGH;
    gpio.Alternate = GPIO_AF5_SPI2;
    HAL_GPIO_Init(DISP_CLK_GPIO_Port, &gpio);

    /* USART3 pin configuration */
    gpio.Pin       = GPS_RX_Pin | GPS_TX_Pin;
    gpio.Mode      = GPIO_MODE_AF_PP;
    gpio.Pull      = GPIO_PULLUP;
    gpio.Speed     = GPIO_SPEED_FREQ_HIGH;
    gpio.Alternate = GPIO_AF7_USART3;
    HAL_GPIO_Init(GPS_RX_GPIO_Port, &gpio);

    return;
}

void vApplicationIdleHook(void)
{
    /* Put CPU to sleep until next interrupt */
    __asm__("WFI");

    return;
}

static void mainTask(void * argument)
{
    int       display[NUM_CNT];
    time_t    utcTime;
    struct tm utcDateTime = {0};
    time_t    localTime;
    struct tm localDateTime = {0};

    //MX_USB_DEVICE_Init();

    timezone_set(&timezoneDST, &timezoneSTD);

    while(true)
    {
        /* Determine current time */
        rtc_getTime(&utcDateTime, NULL);
        utcTime = mktime(&utcDateTime);

        localTime = timezone_toLocal(utcTime);
        localtime_r(&localTime, &localDateTime);

        /* Update nixie tube digits */
        display[0] = localDateTime.tm_hour;
        display[1] = localDateTime.tm_min;
        display[2] = localDateTime.tm_sec;
        nixieDriver_set(display);

        /* Wait for second to increment */
        rtc_wait();
    }
}

static void ledTask(void * argument)
{
    hsv_t hsv = {0.0f, 1.0f, 0.2f};
    rgb_t rgb;

    portTASK_USES_FLOATING_POINT();

    while(true)
    {
        pwm_wait();

        hsv.hue += 0.1f;
        if(hsv.hue >= 360.0f)
        {
            hsv.hue -= 360.0f;
        }

        color_hsvToRgb(&hsv, &rgb);
        color_ledAdjust(&rgb);

        pwm_set(2, rgb.red);
        pwm_set(3, rgb.grn);
        pwm_set(4, rgb.blu);
    }
}


/* Public function definitions ************************************************/
int main(void)
{
#if DEBUG
    initialise_monitor_handles();
#endif /* DEBUG */

    debug_printf("Program start\n");

    /* Reset of all peripherals, Initializes the Flash interface and the Systick. */
    HAL_Init();

    /* Configure the system clock */
    systemClockConfig();

    /* Initialize all configured peripherals */
    gpioInit();

    pwm_init();
    spi_init();
    uart_init();
    rtc_init();
    nixieDriver_init();
    gps_init();

    xTaskCreate(
        mainTask,
        "main",
        128,
        NULL,
        MAIN_TASK_PRIORITY,
        &mainTaskHandle);
    debug_assert(mainTaskHandle);

    xTaskCreate(
        ledTask,
        "led",
        128,
        NULL,
        LED_TASK_PRIORITY,
        &ledTaskHandle);
    debug_assert(ledTaskHandle);

    /* Start scheduler */
    vTaskStartScheduler();

    /* We should never get here as control is now taken by the scheduler */
    return -1;
}

#ifdef USE_FULL_ASSERT
void assert_failed(uint8_t* file, uint32_t line)
{
    while(true);

    return;
}
#endif

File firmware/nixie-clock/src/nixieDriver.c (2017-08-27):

/*******************************************************************************
MIT License

Copyright (c) 2017 Jeff Kubascik

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
THE SOFTWARE IS PROVIDED "AS IS", WITHOUT WARRANTY OF ANY KIND, EXPRESS OR
IMPLIED, INCLUDING BUT NOT LIMITED TO THE WARRANTIES OF MERCHANTABILITY,
FITNESS FOR A PARTICULAR PURPOSE AND NONINFRINGEMENT. IN NO EVENT SHALL THE
AUTHORS OR COPYRIGHT HOLDERS BE LIABLE FOR ANY CLAIM, DAMAGES OR OTHER
LIABILITY, WHETHER IN AN ACTION OF CONTRACT, TORT OR OTHERWISE, ARISING FROM,
OUT OF OR IN CONNECTION WITH THE SOFTWARE OR THE USE OR OTHER DEALINGS IN THE
SOFTWARE.
*******************************************************************************/

/* Includes *******************************************************************/
#include "nixieDriver.h"

#include "globals.h"

#include "FreeRTOS.h"
#include "portmacro.h"
#include "task.h"

#include "debug.h"
#include "stm32f3xx_hal.h"

#include "spi.h"


/* Global variables ***********************************************************/


/* Private definitions ********************************************************/
#define TUBE_CNT     6
#define DIGIT_CNT   10

#define SHIFT_BYTES  8
#define BIT_CNT      (SHIFT_BYTES * 8)


/* Private variables **********************************************************/
static const uint8_t m_nixieBitmap[TUBE_CNT][DIGIT_CNT] =
{
    { 10,  9,  8,  7, 26, 25, 24, 23, 22, 11 },
    { 15, 14, 13, 12, 21, 20, 19, 18, 17, 16 },

    {  2,  1,  0, 31, 30, 29, 28, 27,  4,  3 },
    { 62, 61, 60, 59, 36, 35, 34, 33, 32, 63 },

    { 51, 50, 49, 48, 47, 46, 45, 44, 53, 52 },
    { 56, 55, 54, 43, 42, 41, 40, 39, 58, 57 }
};


/* Private function prototypes ************************************************/
static void hvEnable(bool state);
static void dispEnable(bool state);
static void latchEnable(bool state);

static void clrbit(void* addr, unsigned int cnt);


/* Private function definitions ***********************************************/
static void hvEnable(bool state)
{
    if(state)
    {
        HAL_GPIO_WritePin(HV_EN_GPIO_Port, HV_EN_Pin, GPIO_PIN_SET);
    }
    else
    {
        HAL_GPIO_WritePin(HV_EN_GPIO_Port, HV_EN_Pin, GPIO_PIN_RESET);
    }
}

static void dispEnable(bool state)
{
    /* Output is inverted */
    if(state)
    {
        HAL_GPIO_WritePin(DISP_BL_GPIO_Port, DISP_BL_Pin, GPIO_PIN_RESET);
    }
    else
    {
        HAL_GPIO_WritePin(DISP_BL_GPIO_Port, DISP_BL_Pin, GPIO_PIN_SET);
    }

    return;
}

static void latchEnable(bool state)
{
    /* Output is inverted */
    if(state)
    {
        HAL_GPIO_WritePin(DISP_LE_GPIO_Port, DISP_LE_Pin, GPIO_PIN_RESET);
    }
    else
    {
        HAL_GPIO_WritePin(DISP_LE_GPIO_Port, DISP_LE_Pin, GPIO_PIN_SET);
    }

    return;
}

static void clrbit(void* addr, unsigned int cnt)
{
    uint8_t*     byte = ((uint8_t*)addr) + (cnt / 8);
    unsigned int bit = cnt % 8;

    *byte &= ~(1 << bit);

    return;
}


/* Public function definitions ************************************************/
void nixieDriver_init(void)
{
    hvEnable(true);
    dispEnable(false);

    return;
}

void nixieDriver_set(int* vals)
{
    int     index;
    uint8_t bitmask[SHIFT_BYTES];
    int     tensDigit;
    int     onesDigit;

    memset(bitmask, 0xFF, sizeof(bitmask));

    for(index = 0; index < NUM_CNT; index++)
    {
        tensDigit = vals[index] / DIGIT_CNT;
        onesDigit = vals[index] % DIGIT_CNT;

        if(tensDigit >= DIGIT_CNT)
        {
            tensDigit = DIGIT_CNT-1;
        }

        clrbit(bitmask, m_nixieBitmap[index*2][tensDigit]);
        clrbit(bitmask, m_nixieBitmap[index*2 + 1][onesDigit]);
    }

    vTaskDelay(1);

    latchEnable(false);

    vTaskDelay(1);

    spi_tx(bitmask, SHIFT_BYTES);

    vTaskDelay(1);

    latchEnable(true);

    vTaskDelay(1);

    dispEnable(true);

    return;
}

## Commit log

2017-04-01 Adding preamp board
    [preamp.kicad_pcb, preamp.sch]
2017-04-01 Created schematic PDF
2017-04-01 Moved footprint library into hardware folder
    [preamp.sch]
2017-04-01 Working on clock schematic
    [clock.kicad_pcb, clock.sch]
2017-04-02 Working on schematic
    [clock.sch]
2017-04-02 Split design into two boards
    [main-board.kicad_pcb, main-board.sch, tube-board.kicad_pcb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]
2017-04-02 Working on tube board schematic
    [main-board.sch, tube-board.sch]
2017-04-02 Completed tube board schematic
    [tube-board.sch]
2017-04-02 Working on footprints
    [tube-board.sch]
2017-04-03 Working on tube board layout
    [tube-board.kicad_pcb, tube-board.sch]
2017-04-05 Working on main board schematic
    [main-board.sch, tube-board.kicad_pcb]
2017-04-05 Modified HV5522 footprint to have oval pads
    [tube-board.kicad_pcb]
2017-04-06 Finished tube board
    [tube-board.kicad_pcb, tube-board.sch]
2017-04-09 Working on main board layout
    [main-board.kicad_pcb, main-board.sch]
2017-04-13 Added bypass cap to MAX1771. Cleaning up PCB design
    [main-board.kicad_pcb, main-board.sch]
2017-04-14 Using DIP switch for BOOT mode. Minor layout changes
    [main-board.kicad_pcb, main-board.sch]
2017-04-14 Final tweaks before board submission
    [main-board.kicad_pcb]
2017-04-14 Completed BOMs for both boards
    [main-board.sch, tube-board.sch]
2017-04-14 Working on 3D models for main board
    [main-board.kicad_pcb]
2017-04-14 Fixed BOM part number error on tube-board
    [tube-board.sch]
2017-04-17 Working on enclosure
    [Base1.ipt, Base2.ipt, MainPCB.ipt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]
2017-04-19 Working on lazer cutter drawings
    [Drawing2mmSheet.dwg, Drawing3mmSheet.dwg]
2017-04-20 Changing acrylic thickness to match what is available
    [Back.ipt, Base1.ipt, Base2.ipt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]
2017-04-25 Created laser cutter drawing
    [NixieClock.dwg, NixieClock.iam]
2017-04-28 Created laser cut svg drawings
2017-05-02 Added rubber feet to assembly
    [Bumper.ipt, M3Nut.ipt, M3x25mm.ipt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]
2017-05-08 Removed preamp board. Created firmware project
    [.custom.cfg, main-board.kicad_pcb, nixie-clock.cfg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]
2017-05-09 Debug and RGB LED PWM now working
2017-05-10 Fixed HV5522 footprint on tube board. Increased size of IN-14 through holes. Fixed footprint for MOSFET in HV boost circuit. Fixed hole size for battery holder footprint.
    [main-board.kicad_pcb, main-board.sch, tube-board.kicad_pcb]
2017-05-10 Switched to an 0603 capacitor on tube board
    [tube-board.kicad_pcb, tube-board.sch]
2017-05-11 Modified thermal relief on SMA connector
    [main-board.kicad_pcb]
2017-05-11 Enabled semihosting for printf debugging
2017-05-23 Working on nixie driver module
2017-05-30 Working on display driver module
2017-06-10 Test code for nixie tubes working
2017-06-15 Updated current limit resistors for nixie tubes
    [tube-board.sch]
2017-06-18 Cleaning up nixie driver module
2017-06-21 Added error handler for UART
    [gps.c]
2017-07-05 Working on custom uart driver module
2017-07-06 Working on uart driver
2017-07-07 Now using custom uart driver for reading from gps
2017-07-15 Moved read line function into uart module
2017-07-15 Able to build application with cmake
    [.custom.cfg]
2017-07-18 Working on rtc driver module
2017-07-18 Working on rtc driver
2017-07-19 Working on rtWorking on rtc driver
2017-07-19 RTC wakeup interrupt now working
2017-07-21 Enabled LSE oscillator for RTC clock
    [main.c]
2017-07-26 Added semihosting for printf debugging
2017-08-20 Modified RTC driver to bypass shadow registers
2017-08-21 Using queue to pass timestamp value to gps thread
2017-08-24 Created PWM module to replace the STM32 HAL timer library
    [main.c, pwm.c]
2017-08-24 No longer need floating point support in gps task
    [gps.c]
2017-08-24 Created spi driver module
2017-08-25 Working on SPI driver module
2017-08-27 SPI driver module working
2017-08-27 Cleaning up driver code
2017-08-27 Added function to wait for PWM timer to reload
2017-08-27 Working on RGB LED pattern
2017-08-28 Tweaking pwm timer clock
2017-08-28 Now cycling hues with the RGB LEDs
2017-08-29 Removed unused files
    [nixie-clock.cfg]
2017-08-30 Switched FreeRTOS heap to use stdlib
2017-08-31 Squaring LED brightness value to adjust for perceived intensity
2017-09-04 Added pull up circuit for USB. Changed boot switch to a right angle pushbutton so that it can be used to switch to bootloader mode within the enclosure
    [main-board.kicad_pcb, main-board.sch]
